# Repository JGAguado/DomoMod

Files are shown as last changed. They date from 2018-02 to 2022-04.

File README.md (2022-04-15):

[][releases]
[](LICENSE)

[][maintenance]
[][buymecoffee]

# DomoMod
Mod for ArduLab, directly plugable via the Mod Interface. The DomoMod is designed to enhance the ArduLab functions for domotics aplications: environment monitoring and security systems.

<p float="left">
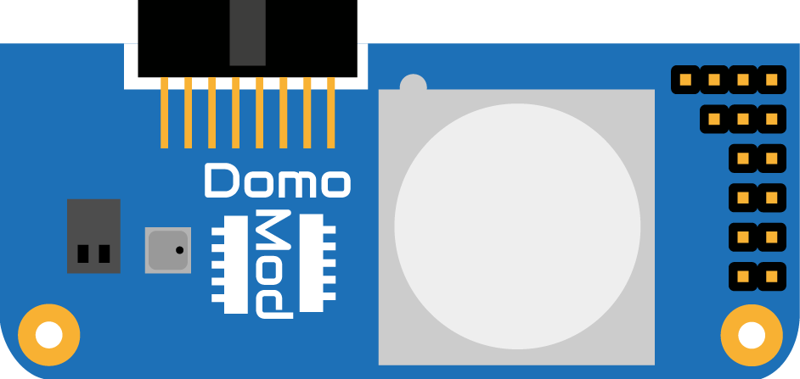
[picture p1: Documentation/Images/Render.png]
   
</p>

## Project tree

<li><a href="./Design/">Design</a></li>
<li><a href="./Documentation/">Documentation</a></li>

<li><a href="./README.md">README.md</a></li>

[releases-shield]: https://img.shields.io/github/release/JGAguado/DomoMod.svg?style=for-the-badge
[releases]: https://github.com/JGAguado/DomoMod/releases

[license-shield]: https://img.shields.io/badge/License-CC%20BY--NC--SA%204.0-lightgrey.svg?style=for-the-badge

[maintenance-shield]: https://img.shields.io/badge/maintainer-J.%20G.%20Aguado-blue.svg?style=for-the-badge
[maintenance]: https://github.com/JGAguado

[buymecoffee-shield]: https://img.shields.io/badge/buy%20me%20a%20coffee-support-yellow.svg?style=for-the-badge
[buymecoffee]: https://www.buymeacoffee.com/J.G.Aguado

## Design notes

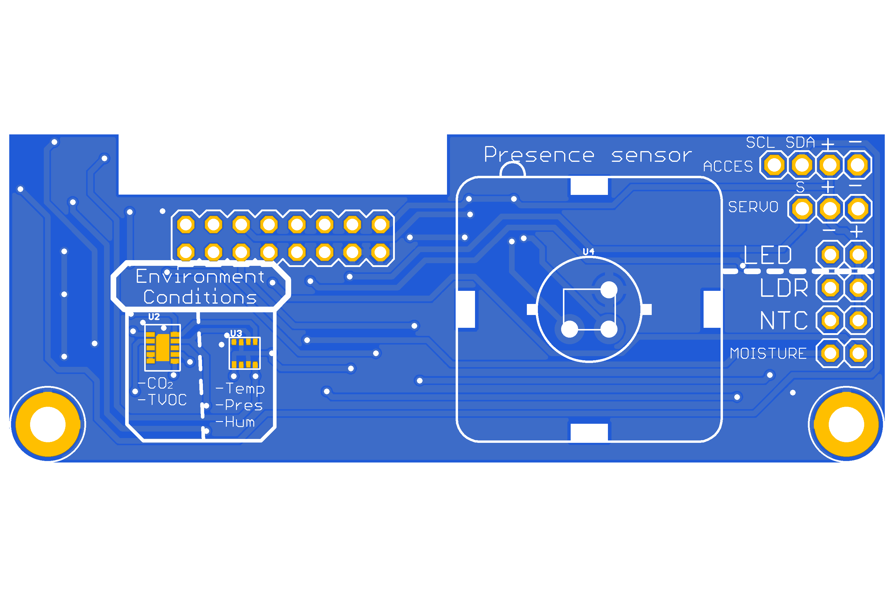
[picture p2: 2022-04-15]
Documentation/Images/Top.png

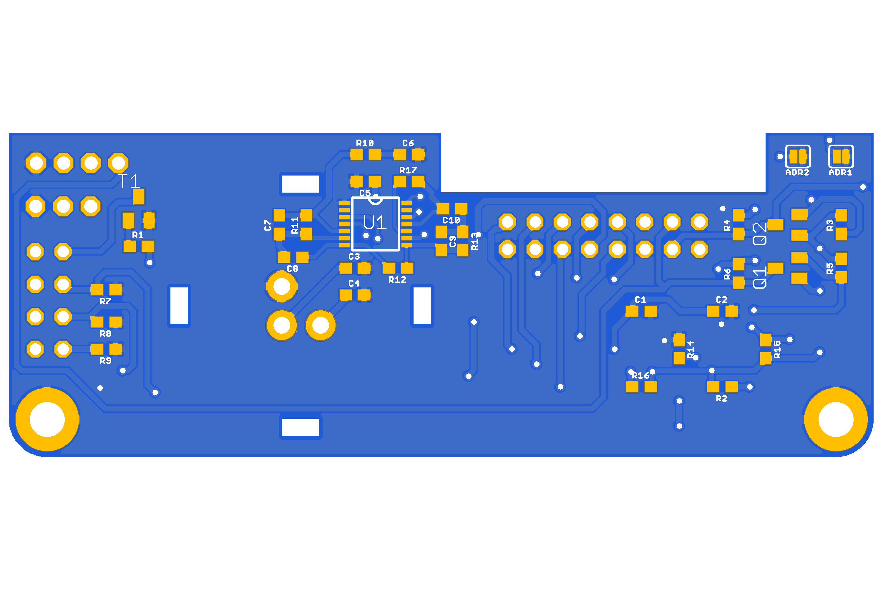
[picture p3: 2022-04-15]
Documentation/Images/Bottom.png

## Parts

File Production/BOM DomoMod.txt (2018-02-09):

Part Value         Device                    Package              Description                                                MF MPN OC_FARNELL OC_NEWARK PROD_ID   VALUE        
ADR1               JUMPER-SMT_2_NO_SILK      SMT-JUMPER_2_NO_SILK Normally open jumper                                                                                          
ADR2               JUMPER-SMT_2_NO_SILK      SMT-JUMPER_2_NO_SILK Normally open jumper                                                                                          
C1   0.1uF         0.1UF-0603-25V-(+80/-20%) 0603                 0.1µF ceramic capacitors                                                               CAP-00810 0.1uF        
C2   1.0uF         1.0UF-0603-16V-10%        0603                 1µF ceramic capacitors                                                                 CAP-00868 1.0uF        
C3   1.0uF         1.0UF-0603-16V-10%        0603                 1µF ceramic capacitors                                                                 CAP-00868 1.0uF        
C4   1.0uF         1.0UF-0603-16V-10%        0603                 1µF ceramic capacitors                                                                 CAP-00868 1.0uF        
C5   1.0uF         1.0UF-0603-16V-10%        0603                 1µF ceramic capacitors                                                                 CAP-00868 1.0uF        
C6   6.9uF         1.0UF-0603-16V-10%        0603                 1µF ceramic capacitors                                                                 CAP-00868 1.0uF        
C7   15nF          1.0UF-0603-16V-10%        0603                 1µF ceramic capacitors                                                                 CAP-00868 1.0uF        
C8   6.9uF         1.0UF-0603-16V-10%        0603                 1µF ceramic capacitors                                                                 CAP-00868 1.0uF        
C9   15nF          1.0UF-0603-16V-10%        0603                 1µF ceramic capacitors                                                                 CAP-00868 1.0uF        
C10  10uF          1.0UF-0603-16V-10%        0603                 1µF ceramic capacitors                                                                 CAP-00868 1.0uF        
H1                 MOUNT-PAD-ROUND3.2        3,2-PAD              MOUNTING PAD, round                                                                                           
H2                 MOUNT-PAD-ROUND3.2        3,2-PAD              MOUNTING PAD, round                                                                                           
JP1                PINHD-1X2                 1X02                 PIN HEADER                                                                                                    
JP2                PINHD-1X2                 1X02                 PIN HEADER                                                                                                    
JP3                PINHD-1X2                 1X02                 PIN HEADER                                                                                                    
JP4                PINHD-1X2                 1X02                 PIN HEADER                                                                                                    
JP5                PINHD-1X3                 1X03                 PIN HEADER                                                                                                    
JP6                PINHD-1X4                 1X04                 PIN HEADER                                                                                                    
Q1   BSS138        MOSFET-NREFLOW            SOT23                N-Channel Mosfet                                                                                              
Q2   BSS138        MOSFET-NREFLOW            SOT23                N-Channel Mosfet                                                                                              
R1   1k            100KOHM-0603-1/10W-1%     0603                 100kO resistor                                                                         RES-07828 100k         
R2   4.7k          4.7KOHM-0603-1/10W-1%     0603                 4.7kO resistor                                                                         RES-07857 4.7k         
R3   10k           100KOHM-0603-1/10W-1%     0603                 100kO resistor                                                                         RES-07828 100k         
R4   10k           100KOHM-0603-1/10W-1%     0603                 100kO resistor                                                                         RES-07828 100k         
R5   10k           100KOHM-0603-1/10W-1%     0603                 100kO resistor                                                                         RES-07828 100k         
R6   10k           100KOHM-0603-1/10W-1%     0603                 100kO resistor                                                                         RES-07828 100k         
R7   10k           100KOHM-0603-1/10W-1%     0603                 100kO resistor                                                                         RES-07828 100k         
R8   10k           100KOHM-0603-1/10W-1%     0603                 100kO resistor                                                                         RES-07828 100k         
R9   10k           100KOHM-0603-1/10W-1%     0603                 100kO resistor                                                                         RES-07828 100k         
R10  47k           100KOHM-0603-1/10W-1%     0603                 100kO resistor                                                                         RES-07828 100k         
R11  4.7M          100KOHM-0603-1/10W-1%     0603                 100kO resistor                                                                         RES-07828 100k         
R12  47k           100KOHM-0603-1/10W-1%     0603                 100kO resistor                                                                         RES-07828 100k         
R13  4.7M          100KOHM-0603-1/10W-1%     0603                 100kO resistor                                                                         RES-07828 100k         
R14  100k          100KOHM-0603-1/10W-1%     0603                 100kO resistor                                                                         RES-07828 100k         
R15  100k          100KOHM-0603-1/10W-1%     0603                 100kO resistor                                                                         RES-07828 100k         
R16  100k          100KOHM-0603-1/10W-1%     0603                 100kO resistor                                                                         RES-07828 100k         
R17  220k          100KOHM-0603-1/10W-1%     0603                 100kO resistor                                                                         RES-07828 100k         
SV1                MA08-2                    MA08-2               PIN HEADER                                                        unknown    unknown                          
T1   MMBT2222A     BC808-NPN-SOT23-BEC       SOT23-BEC            NPN Transistror                                                                                               
U$1  CWM 0.5 GI V1 PIR-LENSCWM-0.5-GI-V1     LENS-CWM-0.5-GI-V1                                                                                                    CWM 0.5 GI V1
U1   BD9251FV      BD9251FV                  TSSOP-14             Amplifier for Pyroelectric Infrared Sensor                                                                    
U2   CCS811        CCS811PRODUCTION          LGA10                AMS CCS811 &ndash; I2C Digital Gas Sensor                                              IC-13607  CCS811       
U3   BME280        BME280                    LGA-8-2.5X2.5        Bosch BME280 &ndash; Combined Humidity and Pressure Sensor                             IC-13090  BME280       
U4   PIR           PIR                       PIR                                                                                                         IC-13430

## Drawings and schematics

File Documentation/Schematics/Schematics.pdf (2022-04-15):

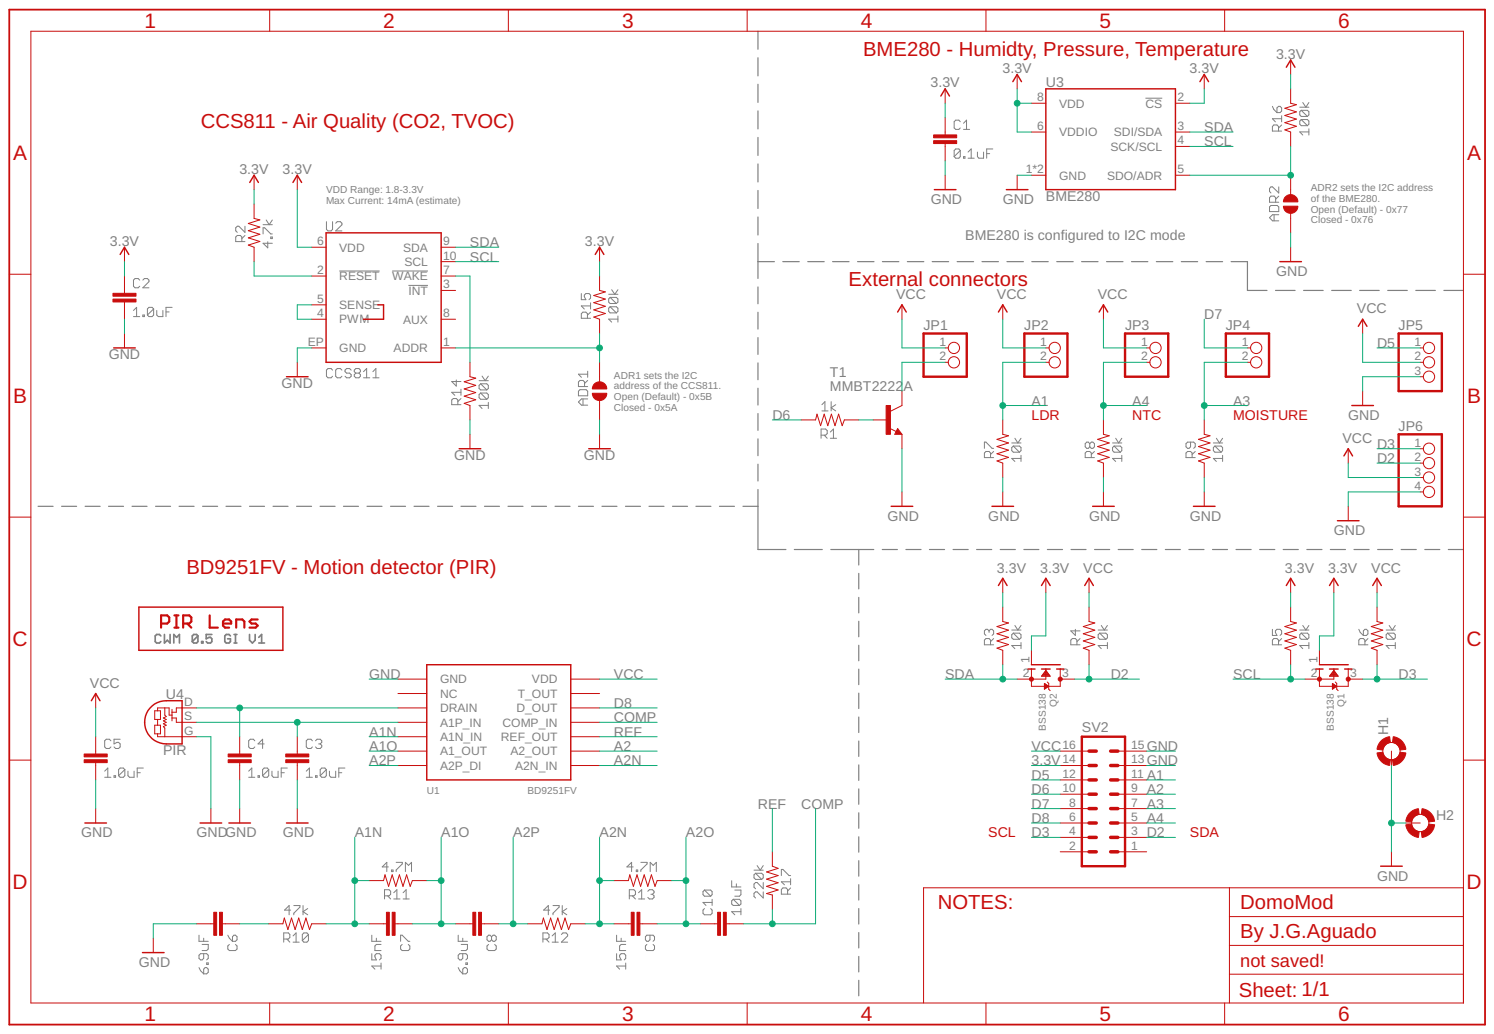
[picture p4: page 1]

VDD Range: 1.8-3.3V Max Current: 14mA (estimate)

ADR2 sets the I2C address of the BME280. Open (Default) - 0x77 Closed - 0x76 BME280 is configured to I2C mode

ADR1 sets the I2C
address of the CCS811. Open (Default) - 0x5B Closed - 0x5A

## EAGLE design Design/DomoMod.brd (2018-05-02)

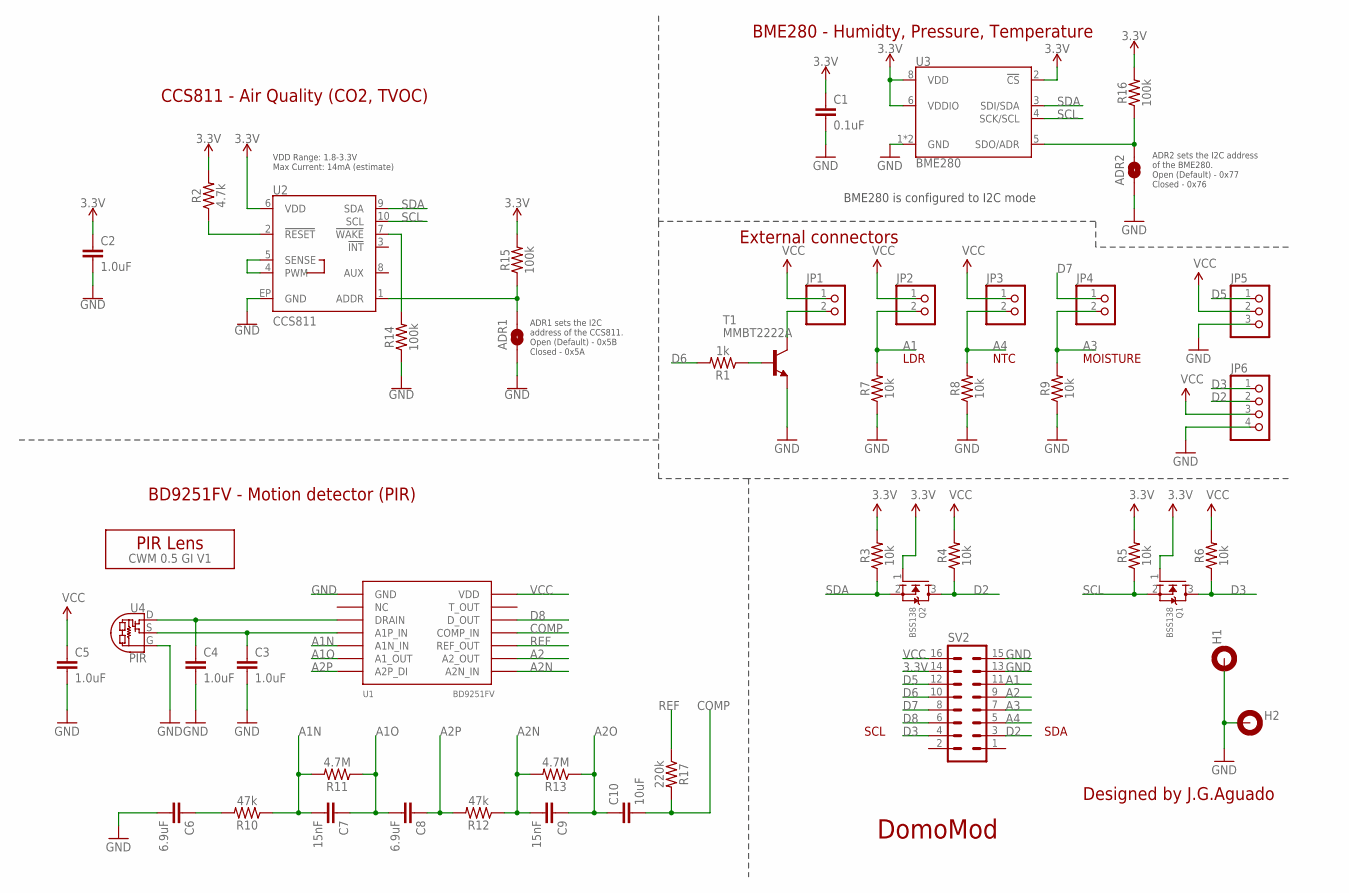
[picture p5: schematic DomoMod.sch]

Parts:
ADR1, ADR2: JUMPER-SMT_2_NO_SILK; SMT-JUMPER_2_NO_SILK
C1: 0.1uF; 0603
C2, C3, C4, C5: 1.0uF; 0603
C6, C8: 6.9uF; 0603
C7, C9: 15nF; 0603
C10: 10uF; 0603
H1, H2: MOUNT-PAD-ROUND3.2; 3,2-PAD
JP1, JP2, JP3, JP4: PINHD-1X2; 1X02
JP5: PINHD-1X3; 1X03
JP6: PINHD-1X4; 1X04
Q1, Q2: BSS138; SOT23
R1: 1k; 0603
R2: 4.7k; 0603
R3, R4, R5, R6, R7, R8, R9: 10k; 0603
R10, R12: 47k; 0603
R11, R13: 4.7M; 0603
R14, R15, R16: 100k; 0603
R17: 220k; 0603
SV2: MA08-2
T1: MMBT2222A; SOT23-BEC
U1: BD9251FV; TSSOP-14
U2: CCS811; LGA10
U3: BME280; LGA-8-2.5X2.5
U4: PIR
U$1: CWM 0.5 GI V1; LENS-CWM-0.5-GI-V1

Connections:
3.3V: C1.1, C2.1, Q1.1 (G), Q2.1 (G), R2.2, R3.2, R5.2, R15.2, R16.2, SV2.14, U2.6 (VDD), U3.2 (!CS), U3.6 (VDDIO), U3.8 (VDD)
!RST: R2.1, U2.2 (!RESET!)
!WAKE: R14.2, U2.7 (!WAKE!)
A1: JP2.2, R7.2, SV2.11
A1N: C7.2, R10.1, R11.2, U1.5 (A1N_IN)
A1O: C7.1, C8.2, R11.1, U1.6 (A1_OUT)
A2: SV2.9, U1.9 (A2_OUT)
A2N: C9.2, R12.1, R13.2, U1.8 (A2N_IN)
A2O: C9.1, C10.1, R13.1
A2P: C8.1, R12.2, U1.7 (A2P_DI)
A3: JP4.2, R9.2, SV2.7
A4: JP3.2, R8.2, SV2.5
CCS811_ADDR: ADR1.2, R15.1, U2.1 (ADDR)
COMP: C10.2, R17.2, U1.11 (COMP_IN)
D2: JP6.2, Q2.3 (D), R4.1, SV2.3
D3: JP6.1, Q1.3 (D), R6.1, SV2.4
D5: JP5.1, SV2.12
D6: R1.2, SV2.10
D7: JP4.1, SV2.8
D8: SV2.6, U1.12 (D_OUT)
GND: ADR1.1, ADR2.1, C1.2, C2.2, C3.2, C4.2, C5.2, C6.2, H1.B3,2, H2.B3,2, JP5.3, JP6.4, R7.1, R8.1, R9.1, R14.1, SV2.13, SV2.15, T1.E, U1.1 (GND), U2.EP (GND), U3.1 (GND), U3.7 (GND), U4.G
unnamed: C6.1, R10.2
unnamed: C3.1, U1.4 (A1P_IN), U4.S
unnamed: C4.1, U1.3 (DRAIN), U4.D
unnamed: JP1.2, T1.C
unnamed: R1.1, T1.B
NTC_SENSE: U2.4 (PWM), U2.5 (SENSE)
REF: R17.1, U1.10 (REF_OUT)
SCL: Q1.2 (S), R5.1, U2.10 (SCL), U3.4 (SCK/SCL)
SDA: Q2.2 (S), R3.1, U2.9 (SDA), U3.3 (SDI/SDA)
SDO/ADR: ADR2.2, R16.1, U3.5 (SDO/ADR)
VCC: C5.1, JP1.1, JP2.1, JP3.1, JP5.2, JP6.3, R4.2, R6.2, SV2.16, U1.14 (VDD)

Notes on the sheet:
DomoMod
Designed by J.G.Aguado
VDD Range: 1.8-3.3V Max Current: 14mA (estimate)
CCS811 - Air Quality (CO2, TVOC)
ADR1 sets the I2C address of the CCS811. Open (Default) - 0x5B Closed - 0x5A
ADR2 sets the I2C address of the BME280. Open (Default) - 0x77 Closed - 0x76
BME280 is configured to I2C mode
BME280 - Humidty, Pressure, Temperature
BD9251FV - Motion detector (PIR)
External connectors
SCL
SDA
LDR
NTC
MOISTURE

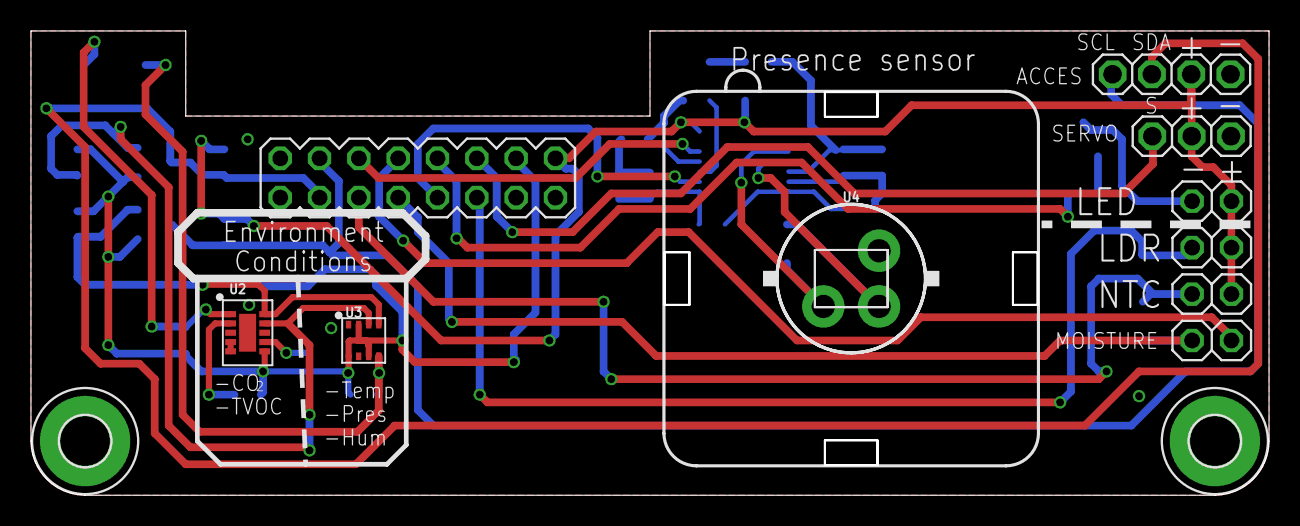
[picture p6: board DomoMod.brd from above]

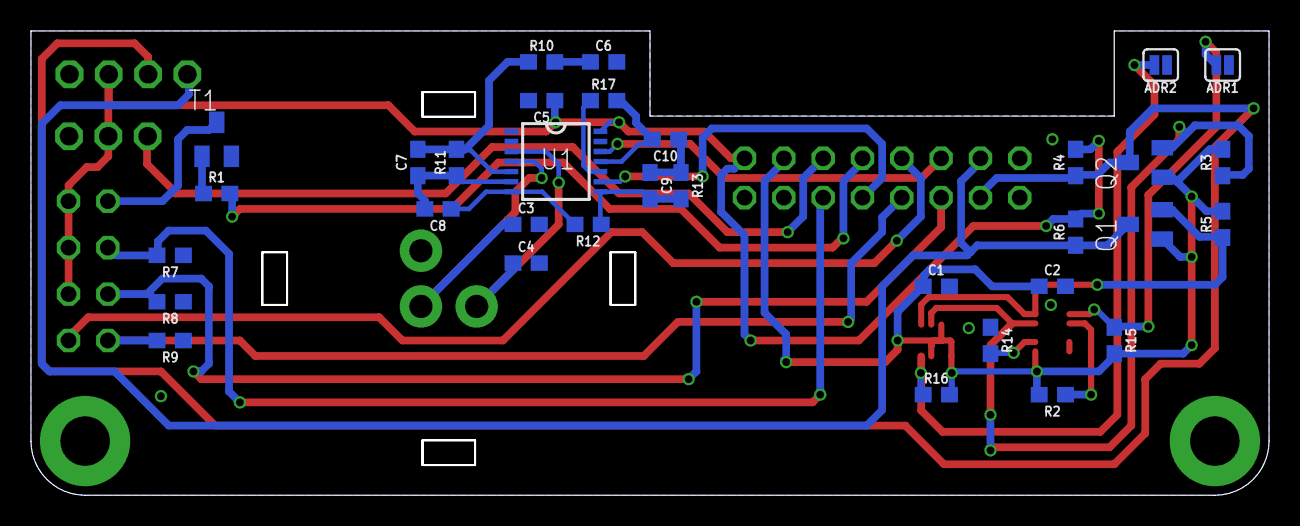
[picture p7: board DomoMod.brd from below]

Board: 2 copper layers, 80.0 x 30.0 mm, 46 parts (33 on the bottom side), 32 nets.

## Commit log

2018-01-10 Added schematics for Temp/Hum and barometric pressure sensor.
    [DomoMod.brd, DomoMod.sch]
2018-01-13 SCH: -Components placed and connected -Documented BRD: -Components placed -100% routed -DRC passed
    [DomoMod.brd, DomoMod.sch]
2018-01-14 GERBER files
    [DomoMod.GBL, DomoMod.GBO, DomoMod.GBP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]
2018-01-14 Added BOM and Centroid file
    [DomoMod_centroid.csv]
2018-01-17 Update gerber for production
    [DomoMod.GBO, DomoMod.GTL, DomoMod.GTO]
2018-01-30 Component replacement: NCS36000 -> BD9251FV
    [DomoMod.brd, DomoMod.sch]
2018-02-01 BRD and Production files updated for component BD9251FV
    [DomoMod.brd, DomoMod.sch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]
2018-02-03 Added Schematics.pdf
    [DomoMod.brd]
2018-02-09 Fixed connector interface (rows were changed)
    [DomoMod.brd, DomoMod.sch]
2018-02-09 Updated BOM
2018-02-09 Updated centroid file
    [DomoMod_centroid.csv]
2018-02-22 Updated Production/DomoMod.GTL
    [DomoMod.GTL]
2018-05-02 Updated design files
    [DomoMod.brd, DomoMod.sch]
2018-05-02 Updated production files
    [DomoMod.GBL, DomoMod.GBS, DomoMod.GTL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]
2022-04-15 Updated structure
    [DomoMod.brd, DomoMod.sch]

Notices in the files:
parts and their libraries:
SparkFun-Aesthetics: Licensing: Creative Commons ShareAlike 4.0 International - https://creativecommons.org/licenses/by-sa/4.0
